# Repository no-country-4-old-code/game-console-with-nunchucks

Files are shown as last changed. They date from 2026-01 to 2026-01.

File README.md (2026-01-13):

# Simple Game Console Based on AtMega87-20PU
This is a minimal gaming console based on two AtMega-MCUs.
The input is done via two old "Wii"-Nunchucks.
Output is given via monitor (VGA) and scores are displayed via 7-segment-displays.

The whole thing is rather old (2013), but I had a lot of fun building it.
In other words: Do not expect much regarding clean code etc.

I translate the original documentation into english using AI and put it below.
And yes.. I did a documentation.. but only because this was needed to publish the project on Heise.
The original documentation with all the nice pictures is also in the repo.

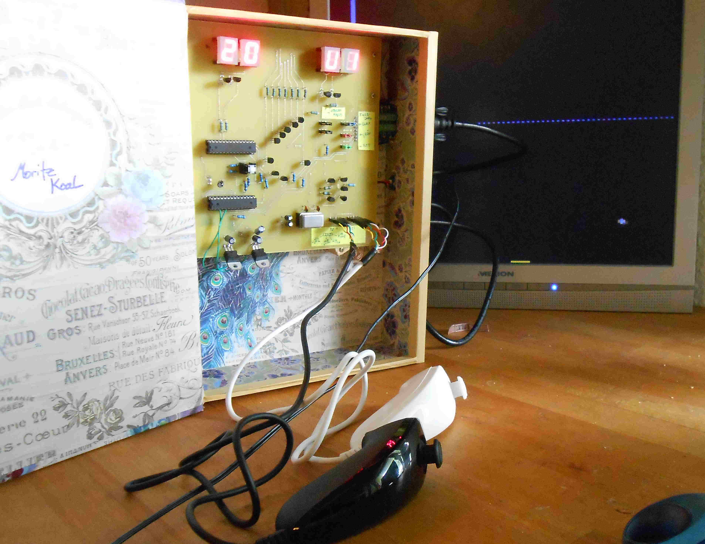
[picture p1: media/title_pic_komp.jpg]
GameConsole


## Documentation (Translated by AI)

## Project Overview

This repository documents a simple video game console that runs the classic game **"Pong"** on a standard VGA monitor, controlled by two Wii Nunchuks. The hardware is powered by just two AtMega88-20PU microcontrollers, and the implementation showcases the technical challenges of VGA signal generation and game logic with limited resources.

## Features

**VGA Output**  
The console directly drives a VGA monitor in 640×480 @60Hz mode, outputting all graphics using the AtMega88 microcontroller. The graphics pipeline and Pong gameplay logic are written in Assembler for maximum performance.

**Controller Support**  
Two original Wii Nunchuks serve as input devices. Their joysticks and accelerometers allow paddle control, selectable via board jumpers. Communication is handled via I²C/TWI.

**Score Display**  
An array of four seven-segment displays shows the current score. Multiplexing and updates are managed in C, running on the second AtMega.

**Additional Controls**  
The board features jumpers for color/mode selection, a reset/start button, and three output pins as triggers for a simple sound system (optional, not included).

**Efficient Communication**  
The microcontrollers communicate via a custom UART protocol for fast score and control updates.

## Technical Highlights

### VGA Module

This unit is responsible for image generation, VGA signaling, game mechanics, and data transfer to the controller module. With the VGA protocol being extremely timing-sensitive, the implementation uses Assembler and overclocks the AtMega88 to 22.1145 MHz.  
The software architecture separates graphics generation (run at 5.5 MHz "pixel clock") and game logic into distinct processes, with a timer ISR acting as the scheduler.

### Controller Module

Implemented in C, this module polls the Nunchuks, manages scores, updates the seven-segment displays, and coordinates with the VGA module via UART. Nunchuk polling and game state updates are all performed within a single frame to maintain responsiveness.

### Hardware Design

Most circuit details are derived from the AtMega88 datasheet and well-known application notes (e.g., Philips AN97055 for level shifting). Special consideration is given to transistor pin layouts, with corrective diagrams provided for BC640 and BS108 variants.

## Notes on VGA Implementation

- **Pixel Clock Limitations:** The microcontroller cannot match the standard 25 MHz VGA pixel clock. Instead, output occurs at roughly 5.5 MHz, resulting in horizontally stretched pixels—but reliable display.
- **Memory Handling:** Graphics data is loaded into SRAM at startup for fast access; worklines and images are organized for efficient redrawing of game elements.
- **UART Datagram:** The UART protocol is custom-designed, using 8 data bits, one stop bit, and a baud rate of 32,143 Kbps.

## Images & Schematics

Key diagrams illustrating VGA timing, connector layouts, software architecture, datagram structure, and transistor pinouts are included in the documentation.

---

### Author

**Moritz Koal** (2013)

---

## Caution on Hardware Layout

When assembling, pay close attention to transistor pin assignments—especially for BC640 (swap collector and base) and BS108 (rotate drain and source by 180°). Refer to the included diagrams and datasheets for exact orientation.

---

## License

Feel free to modify, share, and build upon this project for educational or personal use.

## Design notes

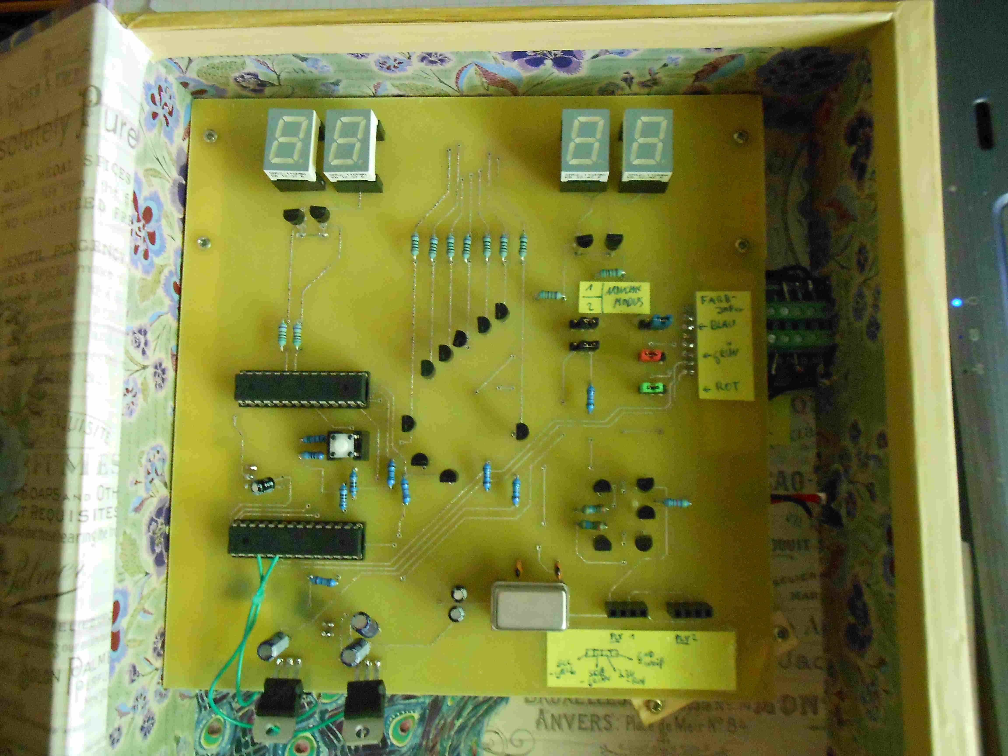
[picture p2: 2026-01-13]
media/von_oben_komp.jpg

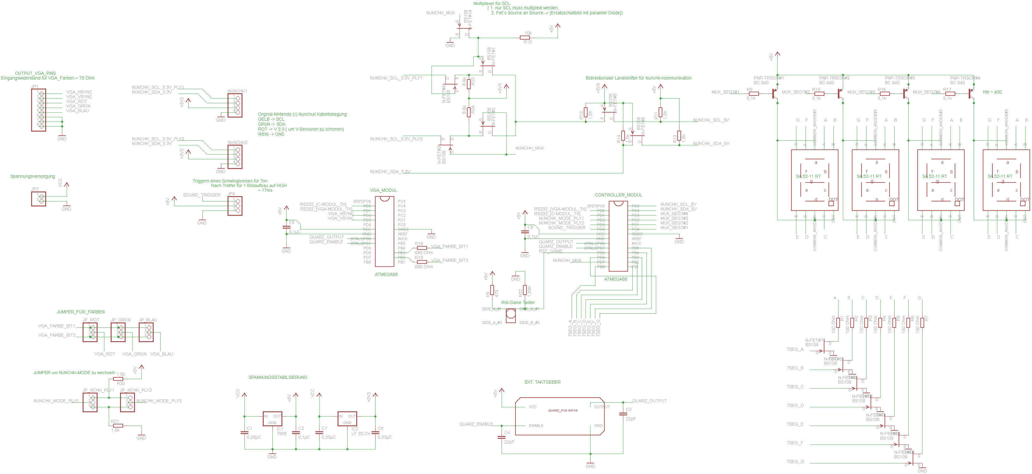
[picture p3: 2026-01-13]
hw/Schaltplan_Spielekonsole.png

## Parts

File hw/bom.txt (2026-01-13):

Stückliste

//======== Eagle

Qty Value            Device             Package                Parts                                                                                                                             Description                
1                    PINHD-1X2          1X02                   JP2                                                                                                                               PIN HEADER                 
6                    PINHD-1X3          1X03                   JP4, JP_BLAU, JP_GRÜN, JP_NCHK_PLY1, JP_NCHK_PLY2, JP_ROT                                                                         PIN HEADER                 
2                    PINHD-1X4          1X04                   NUNCHK1, NUNCHK2                                                                                                                  PIN HEADER                 
1                    PINHD-1X8          1X08                   JP1                                                                                                                               PIN HEADER                 
3   0,1µC            C-EU025-024X044    C025-024X044           C2, C5, C6                                                                                                                        CAPACITOR, European symbol 
3   0,33µC           C-EU025-024X044    C025-024X044           C1, C7, C8                                                                                                                        CAPACITOR, European symbol 
1   1,58k            R-EU_0204/7        0204/7                 R22                                                                                                                               RESISTOR, European symbol  
6   1,5k             R-EU_0204/7        0204/7                 R11, R12, R13, R14, R20, R21                                                                                                      RESISTOR, European symbol  
7   100 Ohm          R-EU_0204/7        0204/7                 R1, R2, R3, R4, R5, R6, R7                                                                                                        RESISTOR, European symbol  
1   10k              R-EU_0204/7        0204/7                 R15                                                                                                                               RESISTOR, European symbol  
2   22pF             C-EU025-024X044    C025-024X044           C3, C4                                                                                                                            CAPACITOR, European symbol 
1   470              R-EU_0204/7        0204/7                 R8                                                                                                                                RESISTOR, European symbol  
4   5,1k             R-EU_0204/7        0204/7                 R9, R10, R16, R17                                                                                                                 RESISTOR, European symbol  
2   680 Ohm          R-EU_0204/7        0204/7                 R18, R19                                                                                                                          RESISTOR, European symbol  
1   7805             78XXL              78XXL                  IC1                                                                                                                               VOLTAGE REGULATOR          
2   8,6k             R-EU_0204/7        0204/7                 R23, R24                                                                                                                          RESISTOR, European symbol  
2   ATMEGA 88-20 PU  ATMEGA8            ATMEGA8_PAC            U$1, U$2                                                                                                                                                     
4   BC 640           2N4126             TO92-CBE               PNP-TRSOR#1, PNP-TRSOR#2, PNP-TRSOR#3, PNP-TRSOR#4                                                                                PNP Transistror            
14  BS108            2N3819             TO92                   N-FET#1, N-FET#2, N-FET#3, N-FET#4, N-FET#5, N-FET#6, N-FET#7, N-FET#8, N-FET#9, N-FET#10, N-FET#11, N-FET#12, N-FET#13, N-FET#14 N-Channel Junction FET     
1   LF 33 CV         78XXL              78XXL                  IC2                                                                                                                               VOLTAGE REGULATOR          
1   QUARZ_PX0_DIP14  QUARZ_PX0_DIP14    QUARZ_PX0_DIP14_PAC    U$3                                                                                                                                                          
4   SA 52-11 RT      SIEBEN_SEG_SA52-11 SIEBEN_SEG_SA52-11_PAC U$4, U$5, U$6, U$7                                                                                                                                           
1   TASTER_1         TASTER_1           TASTER_1_PAC           U$8                                                                                                                                                          

//========== Sonstiges 

2  *	GS 28P-S		IC-Sockel für Atmega88
5  *	MPE 087-1-003		Stiftleisten mit 2,54mm ( für Jumper )
5  *	Jumper 2,54mm		Zur Auswahl Joystick/Beschleunigungssensor etc
8  *	MPE 094-1-005		Buchsenleiste,1X05 2,54mm für Siebensegment Blöcke
4  *	MPE 094-1-004		Buchsenleiste,1X04 2,54mm für Quarz und Nunchucks
2  *	MPE 087-1-004		Stiftleiste,1X04 2,54mm für Nunchucks ( Besser wäre natürlich ein Adapter, so dass man die Nunchucks nicht aufschneiden muss )
1  *	Tastschalter + gegebenfalls entsprechende Buchsenleisten ( z.B. FSM2JH + 2* MPE 094-1-003 )
1  * 	DELOCK 65170		16 Pin, VGA-Buchse <-> Terminalblock. ( Erleichtert den Anschluss )

//========== Stromversorgung
1  *	PSAA 18U-090		Kompaktschaltnetzteil , 18 W , 9 V out
1  *	HEBFL 21		Hohlstecker-Einbaubuchse, Flansch, Stift 2,1mm

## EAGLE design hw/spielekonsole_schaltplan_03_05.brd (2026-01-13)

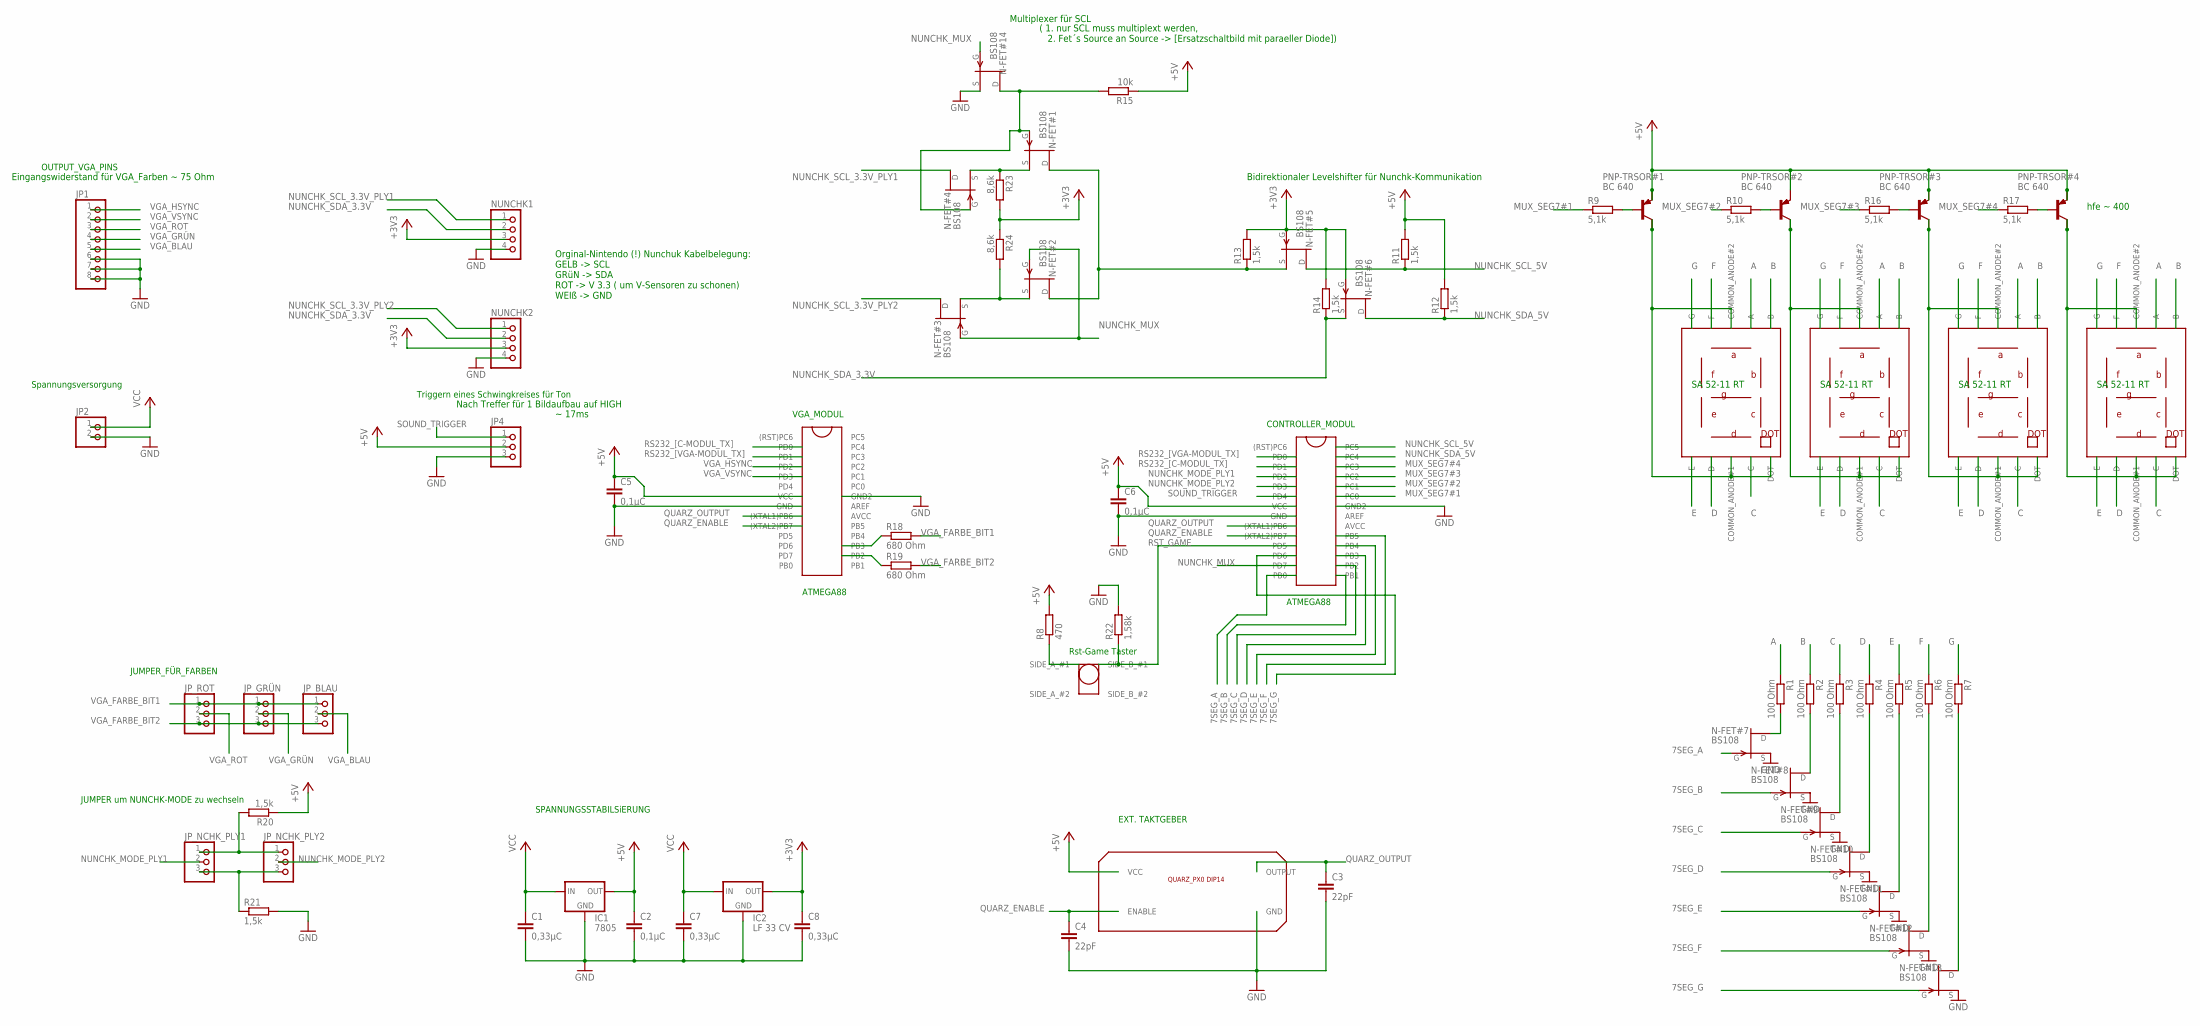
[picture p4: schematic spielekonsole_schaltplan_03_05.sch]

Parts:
C1, C7, C8: 0,33µC; C025-024X044
C2, C5, C6: 0,1µC; C025-024X044
C3, C4: 22pF; C025-024X044
IC1: 7805; 78XXL
IC2: LF 33 CV; 78XXL
JP1: PINHD-1X8; 1X08
JP2: PINHD-1X2; 1X02
JP4: PINHD-1X3; 1X03
JP_BLAU: PINHD-1X3; 1X03
JP_GRÜN: PINHD-1X3; 1X03
JP_NCHK_PLY1, JP_NCHK_PLY2: PINHD-1X3; 1X03
JP_ROT: PINHD-1X3; 1X03
N-FET#1, N-FET#2, N-FET#3, N-FET#4, N-FET#5, N-FET#6, N-FET#7, N-FET#8, N-FET#9, N-FET#10, N-FET#11, N-FET#12, N-FET#13, N-FET#14: BS108; TO92
NUNCHK1, NUNCHK2: PINHD-1X4; 1X04
PNP-TRSOR#1, PNP-TRSOR#2, PNP-TRSOR#3, PNP-TRSOR#4: BC 640; TO92-CBE
R1, R2, R3, R4, R5, R6, R7: 100 Ohm; 0204/7
R8: 470; 0204/7
R9, R10, R16, R17: 5,1k; 0204/7
R11, R12, R13, R14, R20, R21: 1,5k; 0204/7
R15: 10k; 0204/7
R18, R19: 680 Ohm; 0204/7
R22: 1,58k; 0204/7
R23, R24: 8,6k; 0204/7
U$1, U$2: ATMEGA 88-20 PU; ATMEGA8_PAC
U$3: QUARZ_PX0_DIP14; QUARZ_PX0_DIP14_PAC
U$4, U$5, U$6, U$7: SA 52-11 RT; SIEBEN_SEG_SA52-11_PAC
U$8: TASTER_1; TASTER_1_PAC

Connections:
7SEG_A: N-FET#7.2 (G), U$2.PB0
7SEG_B: N-FET#8.2 (G), U$2.PB1
7SEG_C: N-FET#9.2 (G), U$2.PB2
7SEG_D: N-FET#10.2 (G), U$2.PB3
7SEG_E: N-FET#11.2 (G), U$2.PB4
7SEG_F: N-FET#12.2 (G), U$2.PB5
7SEG_G: N-FET#13.2 (G), U$2.PD6
+3V3: C8.1, IC2.OUT, N-FET#5.2 (G), N-FET#6.2 (G), NUNCHK1.3, NUNCHK2.3, R13.2, R14.2, R23.2, R24.1
+5V: C2.1, C5.1, C6.1, IC1.OUT, JP4.2, PNP-TRSOR#1.E, PNP-TRSOR#2.E, PNP-TRSOR#3.E, PNP-TRSOR#4.E, R8.2, R11.2, R12.2, R15.1, R20.1, U$1.VCC, U$2.VCC, U$3.VCC
A: R1.1, U$4.A, U$5.A, U$6.A, U$7.A
B: R2.1, U$4.B, U$5.B, U$6.B, U$7.B
C: R3.1, U$4.C, U$5.C, U$6.C, U$7.C
D: R4.1, U$4.D, U$5.D, U$6.D, U$7.D
E: R5.1, U$4.E, U$5.E, U$6.E, U$7.E
ENABLE_SEG7#1: PNP-TRSOR#1.C, U$4.COMMON_ANODE#1, U$4.COMMON_ANODE#2, U$4.DOT
ENABLE_SEG7#2: PNP-TRSOR#2.C, U$5.COMMON_ANODE#1, U$5.COMMON_ANODE#2, U$5.DOT
ENABLE_SEG7#3: PNP-TRSOR#3.C, U$6.COMMON_ANODE#1, U$6.COMMON_ANODE#2, U$6.DOT
ENABLE_SEG7#4: PNP-TRSOR#4.C, U$7.COMMON_ANODE#1, U$7.COMMON_ANODE#2, U$7.DOT
F: R6.1, U$4.F, U$5.F, U$6.F, U$7.F
G: R7.1, U$4.G, U$5.G, U$6.G, U$7.G
GND: C1.2, C2.2, C3.2, C4.2, C5.2, C6.2, C7.2, C8.2, IC1.GND, IC2.GND, JP1.6, JP1.7, JP1.8, JP2.2, JP4.3, N-FET#7.3 (S), N-FET#8.3 (S), N-FET#9.3 (S), N-FET#10.3 (S), N-FET#11.3 (S), N-FET#12.3 (S), N-FET#13.3 (S), N-FET#14.3 (S), NUNCHK1.4, NUNCHK2.4, R21.2, R22.2, U$1.GND1 (GND), U$1.GND2, U$2.GND1 (GND), U$2.GND2, U$3.GND
MUX_SEG7#1: R9.1, U$2.PC0
MUX_SEG7#2: R10.1, U$2.PC1
MUX_SEG7#3: R16.1, U$2.PC2
MUX_SEG7#4: R17.1, U$2.PC3
unnamed: R8.1, U$8.SIDE_A_#1
unnamed: PNP-TRSOR#1.B, R9.2
unnamed: PNP-TRSOR#2.B, R10.2
unnamed: PNP-TRSOR#3.B, R16.2
unnamed: PNP-TRSOR#4.B, R17.2
unnamed: R18.1, U$1.PB3
unnamed: R19.1, U$1.PB2
unnamed: JP_NCHK_PLY1.3, JP_NCHK_PLY2.3, R21.1
unnamed: N-FET#1.2 (G), N-FET#4.2 (G), N-FET#14.1 (D), R15.2
unnamed: JP_NCHK_PLY1.1, JP_NCHK_PLY2.1, R20.2
unnamed: N-FET#1.1 (D), N-FET#2.1 (D), N-FET#5.3 (S), R13.1
unnamed: N-FET#1.3 (S), N-FET#4.3 (S), R23.1
unnamed: N-FET#2.3 (S), N-FET#3.3 (S), R24.2
unnamed: N-FET#7.1 (D), R1.2
unnamed: N-FET#8.1 (D), R2.2
unnamed: N-FET#9.1 (D), R3.2
unnamed: N-FET#10.1 (D), R4.2
unnamed: N-FET#11.1 (D), R5.2
unnamed: N-FET#12.1 (D), R6.2
unnamed: N-FET#13.1 (D), R7.2
NUNCHK_MODE_PLY1: JP_NCHK_PLY1.2, U$2.PD2
NUNCHK_MODE_PLY2: JP_NCHK_PLY2.2, U$2.PD3
NUNCHK_MUX: N-FET#2.2 (G), N-FET#3.2 (G), N-FET#14.2 (G), U$2.PD7
NUNCHK_SCL_3.3V_PLY1: N-FET#4.1 (D), NUNCHK1.1
NUNCHK_SCL_3.3V_PLY2: N-FET#3.1 (D), NUNCHK2.1
NUNCHK_SCL_5V: N-FET#5.1 (D), R11.1, U$2.PC5
NUNCHK_SDA_3.3V: N-FET#6.3 (S), NUNCHK1.2, NUNCHK2.2, R14.1
NUNCHK_SDA_5V: N-FET#6.1 (D), R12.1, U$2.PC4
QUARZ_ENABLE: C4.1, U$1.PB7 ((XTAL2)PB7), U$2.PB7 ((XTAL2)PB7), U$3.ENABLE
QUARZ_OUTPUT: C3.1, U$1.PB6 ((XTAL1)PB6), U$2.PB6 ((XTAL1)PB6), U$3.OUTPUT
RS232_[C-MODUL_TX]: U$1.PD0, U$2.PD1
RS232_[VGA-MODUL_TX]: U$1.PD1, U$2.PD0
RST_GAME: R22.1, U$2.PD5, U$8.SIDE_B_#1
SOUND_TRIGGER: JP4.1, U$2.PD4
VCC: C1.1, C7.1, IC1.IN, IC2.IN, JP2.1
VGA_BLAU: JP1.5, JP_BLAU.2
VGA_FARBE_BIT1: JP_BLAU.1, JP_GRÜN.1, JP_ROT.1, R18.2
VGA_FARBE_BIT2: JP_BLAU.3, JP_GRÜN.3, JP_ROT.3, R19.2
VGA_GRÜN: JP1.4, JP_GRÜN.2
VGA_HSYNC: JP1.1, U$1.PD2
VGA_ROT: JP1.3, JP_ROT.2
VGA_VSYNC: JP1.2, U$1.PD3

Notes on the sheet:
OUTPUT_VGA_PINS
JUMPER_FÜR_FARBEN
VGA_MODUL
SPANNUNGSSTABILSiERUNG
Spannungsversorgung
EXT. TAKTGEBER
CONTROLLER_MODUL
ATMEGA88
JUMPER um NUNCHK-MODE zu wechseln
Triggern eines Schwingkreises für Ton
Rst-Game Taster
Orginal-Nintendo (!) Nunchuk Kabelbelegung: GELB -> SCL GRüN -> SDA ROT -> V 3.3 ( um V-Sensoren zu schonen) WEIß -> GND
Multiplexer für SCL
Bidirektionaler Levelshifter für Nunchk-Kommunikation
hfe ~ 400
Eingangswiderstand für VGA_Farben ~ 75 Ohm
Nach Treffer für 1 Bildaufbau auf HIGH
~ 17ms
( 1. nur SCL muss multiplext werden, 2. Fet´s Source an Source -> [Ersatzschaltbild mit paraeller Diode])
SA 52-11 RT

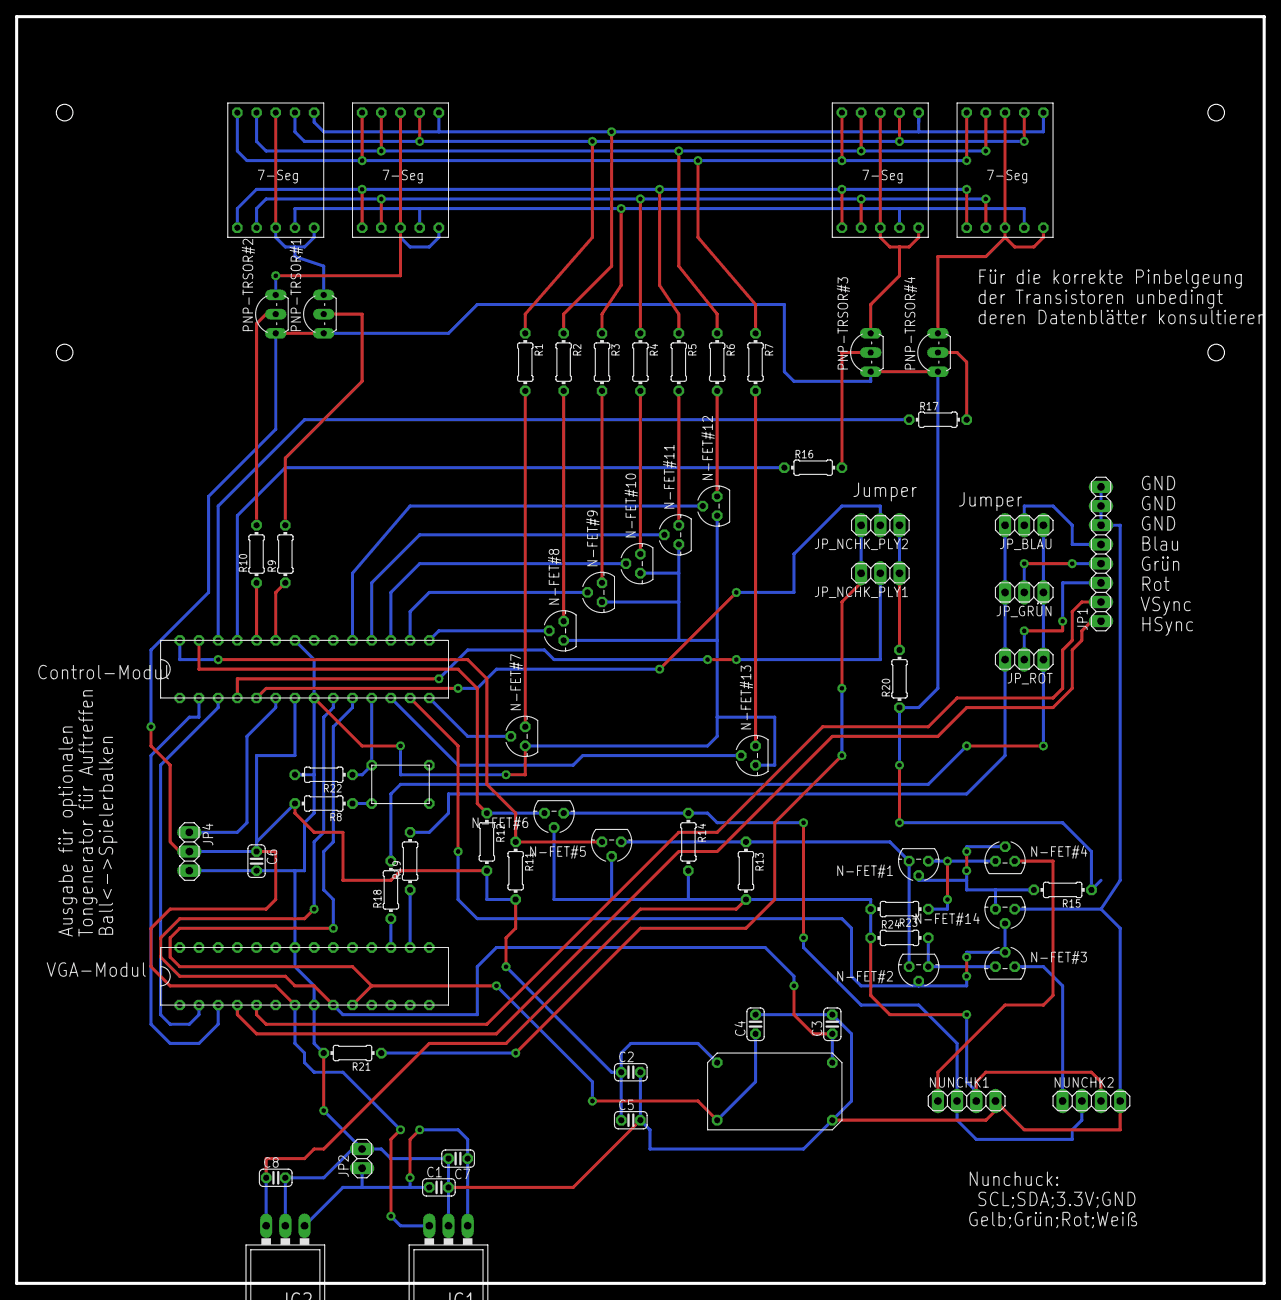
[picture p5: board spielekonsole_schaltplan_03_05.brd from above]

Board: 2 copper layers, 165.1 x 167.6 mm, 70 parts (0 on the bottom side), 67 nets.

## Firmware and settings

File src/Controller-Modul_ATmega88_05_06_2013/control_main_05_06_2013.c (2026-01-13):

/*
 * Project_C.c
 *
 * Created: 24.11.2012 17:46:01
 *  Author: mo
 */ 
//Include Header Dateien in
// C:\Program Files\Atmel\Atmel Studio 6.0\extensions\Atmel\AVRGCC\3.4.0.65\AVRToolchain\avr\include\avr


#define F_CPU 21145000UL

#include <avr/io.h>
#include <string.h>
#include <avr/interrupt.h>
#include <util/delay.h>
#include "uart.h"
#include "twi_routines.h"
#include "funktions.h"


// Rst Knopf
#define RST_PORT PORTD
#define RST_PINS PIND
#define RST_DDR DDRD
#define RST_PIN PD5
#define RST_ACTIV 1 // High Aktiv

// Watchdog
#define BORDER_WATCHDOG 21 // Ein Timer ISR wird standardmäßig mit 60Hz ausgelöst sprich alle 16,6 ms -> Multiplexing geschieht alle 1,6 ms; Grenze wird mit 21 angegeben


// Nunchk-Mode auswählen ( Stick oder Beschleunigungssensor auslesen )
#define NUNCHK_MODE_PORT PORTD
#define NUNCHK_MODE_PINS PIND
#define NUNCHK_MODE_DDR DDRD
#define NUNCHK_MODE_PIN_PLY1 PD2
#define NUNCHK_MODE_PIN_PLY2 PD3
#define NUNCHK_MODE_STICK 1
#define NUNCHK_MODE_VSENSOR 0
#define NUNCHK_MODE_STICK_SEGMENT 0
#define NUNCHK_MODE_VSENSOR_SEGMENT 2


// 'Pong'-Ton Ausgabe
#define SOUND_PORT PORTD
#define SOUND_DDR DDRD
#define SOUND_PIN PD4
#define SOUND_AKTIV 1 // immer über einen Zyklus (also ~ 1/60 s aktiv -> außer beim aufhängen .... ) -> abfange routine in Timer-ISR

// SiebenSeg
#define SEG7_OUTPUT1_PORT PORTB
#define SEG7_OUTPUT2_PORT PORTD
#define SEG7_OUTPUT1_DDR DDRB
#define SEG7_OUTPUT2_DDR DDRD
#define SEG7_OUTPUT_PINS1  0b00111111//(1<<PB0)|(1<<PB1)|(1<<PB2)|(1<<PB3)|(1<<PB4)|(1<<PB5)  //0b00111111 // PB0 bis PB5
#define SEG7_OUTPUT_PINS2  0b01000000//(1<< PD6)  //0b01000000 // PD6 als 7ter Pin
#define NUM_OF_SEG7_DISPLAYS 4
#define NUM_OF_NUMBERS4DISPLAY 10 // Bei Änderung das Array "seg7_umwandlung_zahl2seg7" anpassen !

#define SEG7_MUX_PORT PORTC
#define SEG7_MUX_DDR DDRC
#define SEG7_MUX_PINS 0x0F // PC3:PC0

//Timer0
#define TIMER0_PRESCALER 0x05
#define TIMER0_START_VALUE (255-35) // 35 Takte sollen gezählt werden -> ~1,66 ms


// Nunchk
#define NUNCHUCK_ADR 0x52

#define NUNCHUCK_INIT_1 0xF0 // 1
#define NUNCHUCK_INIT_2 0x55
#define NUNCHUCK_INIT_3 0xFB // 2
#define NUNCHUCK_INIT_4 0x00
#define NUNCHUCK_RST_PTR_RAM 0x00 // 3

#define NUNCHUCK_TIME_INIT_ms 100
#define NUNCHUCK_TIME_RAM_ms 1

#define NUM_OF_NUNCHK_DATA 6

// Für Nunchuck Multiplexer
#define MULTI_NUCHK_PIN PD7
#define MULTIPLI_NUCHK_PORT PORTD
#define MULTIPLI_NUCHK_DDR DDRD
#define TIME_AFTER_CHANGE_NUCHK_us 1
#define NUNCHK_1 0
#define NUNCHK_2 1
#define NUNCHK_CHANGE (1<<MULTI_NUCHK_PIN) // einfach eor mit Nunchk_change um  [ eor ==  ^  ]


// Bewerten einer Bewegung -> Kommunikationsdaten vom Nunchuck
/*nunchk_buffer[     1   ] | [    2    ] | [    3    ] | [    4   ] | [    5     ] | [             6            ] -> 6 Bytes!
 	Bedeutung:	Joystick X | Joystick Y  | V-Sensor X  | V-Sensor Y |  V-Sensor Z  | LSB von X,Y,Z und Knöpfe Z,C 		
*/
#define MOVEMENT_BLANK 0 // welcher Abschnitt wird als Bewegung gewertet
#define MOVEMENT_BORDER_RIGHT 127+30 // Grenzen ab wann Bewegung als Bewegung gezählt werden kann (rausfiltern von Rauschen,leichten Schwankungen)
#define MOVEMENT_BORDER_LEFT 127-30
#define MOVEMENT_BORDER_RIGHT_FAST 127+90
#define MOVEMENT_BORDER_LEFT_FAST 127-90
#define MOVEMENT_RIGHT_PLY1_FAST 0b00000110
#define MOVEMENT_RIGHT_PLY2_FAST 0b00110000
#define MOVEMENT_RIGHT_PLY1 0b00000101
#define MOVEMENT_RIGHT_PLY2 0b00101000
#define MOVEMENT_LEFT_PLY1_FAST	0b00000010
#define MOVEMENT_LEFT_PLY2_FAST	0b00010000
#define MOVEMENT_LEFT_PLY1	0b00000001
#define MOVEMENT_LEFT_PLY2	0b00001000
/*
Kommando für VGA-MODUL : 
Aufbau Protokoll ( C-Modul -> VGA-Modul ) : [ 7:6 | 5:3 | 2:0  ]  == [ 11=rst | BewegungPlayer2 | BewegungPlayer1 ]
*/
#define CMD4VGA_RESET 0b11000000

/*
Kommando für C-MODUL : 
Aufbau Protokoll ( VGA-Modul -> C-Modul ) : [ 7:2 | 1 | 0 ] == [ reserviert ( zu belegen mit "101010" ) | ÄnderungSpielstand2 | ÄnderungSpielstand1 ]
*/
#define CMD4C_NORMAL 0b10101000
#define CMD4C_MASK_POINT_PLY1 0x01
#define CMD4C_MASK_POINT_PLY2 0x02





void nunchuck_init(void);
void nunchuck_receiveData(uint8_t *buffer);
void display_7_segmentanzeige(void);

//globale Variabeln (volatile für ISR-Verwendbarkeit)

volatile uint8_t cmd_data=CMD4VGA_RESET; // enthält zu sendendes Kommando für das VGA-Modul
volatile uint8_t seg7_aktive_anzeige=0; // gibt an welche anzeige grade aktiv ist ( notwendig aufgrund multiplexing )
volatile uint8_t watchdog_counter=0; //Reagiert wenn lange keine RSR232-ISR mehr ausgeführt wurde, um Deadlock zu verhindern. 
uint8_t volatile seg7_zahlenwerte[NUM_OF_SEG7_DISPLAYS]={1,2,3,4}; // die jeweiligen Zahlenwerte ,die angezeigt werden sollen ( 1:0 [Player1] ; 3:2 [Player2] )
uint8_t volatile seg7_umwandlung_zahl2seg7[NUM_OF_NUMBERS4DISPLAY]={0x3F,0x06,0x5B,0x4F,0x66,0x6D,0x7D,0x07,0x7F,0x6F}; // High-aktiv [ hat eine Treiberstufe dahinter ] , Zahlen 0 bis 9
uint8_t volatile seg7_multiplex_werte[NUM_OF_SEG7_DISPLAYS]={0x07,0x0B,0x0D,0x0E}; // PC3:PC0 // LOW Aktiv



uint8_t tmp=0;



//char nunchk_output[42];


int main(void)
{	
	cli();
	// Init RST_PIN
	RST_DDR&=(~(1<<RST_PIN)); // ist ein Eingang !
	RST_PORT&=(~(1<<RST_PIN));
	
	// Init Sound Pin
	SOUND_PORT&=~(SOUND_AKTIV<<SOUND_PIN); // Startet im inaktiven Zustand
	SOUND_DDR|=(1<<SOUND_PIN);
	
	// Init Nunchk_mode Pins
	NUNCHK_MODE_PORT&=~((1<< NUNCHK_MODE_PIN_PLY1 ) | ( 1<< NUNCHK_MODE_PIN_PLY2));
	NUNCHK_MODE_DDR&=~((1<< NUNCHK_MODE_PIN_PLY1 ) | ( 1<< NUNCHK_MODE_PIN_PLY2));
	
	// Init Siebensegmentanzeige + deren Multiplexer
	SEG7_OUTPUT1_DDR|=SEG7_OUTPUT_PINS1;
	SEG7_OUTPUT2_DDR|=SEG7_OUTPUT_PINS2;
	SEG7_MUX_DDR|=SEG7_MUX_PINS;
	SEG7_OUTPUT1_PORT&=~SEG7_OUTPUT_PINS1;
	SEG7_OUTPUT2_PORT|=SEG7_OUTPUT_PINS2;
	SEG7_MUX_PORT&=~SEG7_MUX_PINS;
	
	// Init TimerISR
	TCCR0B=TIMER0_PRESCALER;
	TCNT0=TIMER0_START_VALUE;
	TIMSK0|=(1<<TOIE0); // ISR enablen
	
	// Init des Multiplexers für Nunchuck
	tmp = (1 << MULTI_NUCHK_PIN);
	MULTIPLI_NUCHK_DDR |= tmp;
	MULTIPLI_NUCHK_PORT &= ~tmp;
	
	// Init der Nunchuks
	twi_master_init();	

	MULTIPLI_NUCHK_PORT&=(~(1<<MULTI_NUCHK_PIN)); //ändert des Multiplexers auf Nuchk1
	_delay_ms(TIME_AFTER_CHANGE_NUCHK_us);
	nunchuck_init(); //Nunchuk in decodierten Modus versetzen
	MULTIPLI_NUCHK_PORT^=NUNCHK_CHANGE;
	_delay_ms(TIME_AFTER_CHANGE_NUCHK_us); // Berücksichtigen der Rise and Fall Time des MultiplexerTransistors
	nunchuck_init(); //Nunchuk in decodierten Modus versetzen
	MULTIPLI_NUCHK_PORT^=NUNCHK_CHANGE;
	_delay_ms(TIME_AFTER_CHANGE_NUCHK_us); // Berücksichtigen der Rise and Fall Time des MultiplexerTransistors



	USART_Init(42);
	//für RX-ISR	
	UCSR0B|= (1<<RXCIE0);

	display_7_segmentanzeige();
	
	cmd_data=CMD4VGA_RESET; //Vorher Reset damit auch alles Schön aussieht
	USART_Transmit(cmd_data);
	cmd_data=0;
	
	// Warten auf Knopfdruck
	tmp=RST_PINS & (RST_ACTIV<<RST_PIN);
	
	while(tmp!=(RST_ACTIV<<RST_PIN)){
		tmp=RST_PINS & (RST_ACTIV<<RST_PIN);
	};		
		
	// Reseten vom VGA-Modul 
	cmd_data=CMD4VGA_RESET;
	USART_Transmit(cmd_data);
	cmd_data=0;
	sei();

	
	while(1)
    { 		
	display_7_segmentanzeige();
	if(watchdog_counter>=BORDER_WATCHDOG){
		cmd_data=MOVEMENT_BLANK;  //Vermeidung von Dead-Locks
		USART_Transmit(cmd_data); //ein dummy losschicken, um anderen anzutriggern (der wartet auf eine Antwort) 
		watchdog_counter=0;
		}
	};
	
}


// Funktion zum Ansteuern der 7 Seg Anzeige
// langer Interrupt ,wobei nur anfang ununterbrechbar ist 
ISR(USART_RX_vect){
	cli();
	
	uint8_t new_data;
	uint8_t cmd_prototyp=MOVEMENT_BLANK;
	uint8_t nunchk_buffer[NUM_OF_NUNCHK_DATA];
	uint8_t nunchk_mode=NUNCHK_MODE_STICK_SEGMENT; // Default auf Stick
	
	new_data=UDR0; // liest Zeichen und speichert es in new_data
	
	SOUND_PORT&=~(SOUND_AKTIV<<SOUND_PIN); // Sound aus

	USART_Transmit(cmd_data); 	// sendet Bewegungsbefehle (vorher schon beschlossen)
	
	// wertet Zeichen aus und greift auf 7-Segmentdata zu -> ( 1:0 [Player1] ; 3:2 [Player2] )
	tmp=new_data;
	sei();
	watchdog_counter=0;
	tmp=new_data;
	
	tmp&=CMD4C_MASK_POINT_PLY1;
	//tmp/=CMD4C_MASK_POINT_PLY1; // ergibt 1 bei Übereinstimmung,ansosnten null
// Punkt Sound
	if(tmp==1){	
		SOUND_PORT|=(SOUND_AKTIV<<SOUND_PIN);
	}
	seg7_zahlenwerte[0]+=tmp;
	tmp=seg7_zahlenwerte[0]/NUM_OF_NUMBERS4DISPLAY; // 1 beim übereinstimmen
	seg7_zahlenwerte[0]=seg7_zahlenwerte[0]%NUM_OF_NUMBERS4DISPLAY; // 0 beim Ende des Zahlenspektrums
	seg7_zahlenwerte[1]+=tmp; // wird ein hochgezählt
	seg7_zahlenwerte[1]=seg7_zahlenwerte[1]%NUM_OF_NUMBERS4DISPLAY; // 0 beim Ende des Zahlenspektrums
		
	tmp=new_data;

	tmp&= CMD4C_MASK_POINT_PLY2;
	tmp=tmp >> 1;
	//tmp/=CMD4C_MASK_POINT_PLY2; // ergibt 1 bei Übereinstimmung,ansosnten null
// Punkt Sound
	if(tmp==1){	
		SOUND_PORT|=(SOUND_AKTIV<<SOUND_PIN);
	}
	seg7_zahlenwerte[2]+=tmp;
	tmp=seg7_zahlenwerte[2]/NUM_OF_NUMBERS4DISPLAY; // 1 beim übereinstimmen
	seg7_zahlenwerte[2]=seg7_zahlenwerte[2]%NUM_OF_NUMBERS4DISPLAY; // 0 beim Ende des Zahlenspektrums
	seg7_zahlenwerte[3]+=tmp; // wird ein hochgezählt
	seg7_zahlenwerte[3]=seg7_zahlenwerte[3]%NUM_OF_NUMBERS4DISPLAY; // 0 beim Ende des Zahlenspektrums
	
	
// nur bei Rst zurücksetzen

		
	
//Holen && Auswerten der Daten
/*nunchk_buffer[     1   ] | [    2    ] | [    3    ] | [    4   ] | [    5     ] | [             6            ]
		Bedeutung:	Joystick X | Joystick Y  | V-Sensor X  | V-Sensor Y |  V-Sensor Z  | LSB von X,Y,Z und Knöpfe Z,C 
*/

// MOVEMENT_UNIT -> JOYSTICKX,JOYSTICKY,V-SENSORX,V-SENSORY,V-SENSOR ;

	display_7_segmentanzeige();	

//=== Mode für Nunchk1 bestimmen === [Ob Stick oder V-Sensor für Bewegung relevant -> wird extern über Jumper netschieden ]	

	tmp=NUNCHK_MODE_PINS;
	tmp&=(1<<NUNCHK_MODE_PIN_PLY1);
	if(tmp==(NUNCHK_MODE_STICK<<NUNCHK_MODE_PIN_PLY1)){
		nunchk_mode=NUNCHK_MODE_STICK_SEGMENT;
	}
	else{
		nunchk_mode=NUNCHK_MODE_VSENSOR_SEGMENT;
	}
	
	
//=== Daten vom Nunchk 1 holen ===
	nunchuck_receiveData(&nunchk_buffer[0]);
	
	MULTIPLI_NUCHK_PORT^=NUNCHK_CHANGE;
	_delay_ms(TIME_AFTER_CHANGE_NUCHK_us); // Berücksichtigen der Rise and Fall Time des MultiplexerTransistors

	if(nunchk_buffer[nunchk_mode]>=(MOVEMENT_BORDER_RIGHT_FAST)){
		cmd_prototyp|=MOVEMENT_RIGHT_PLY1_FAST; // je nach tmp wird nur die richtige Stelle übernommen
	}
	else if(nunchk_buffer[nunchk_mode]>=(MOVEMENT_BORDER_RIGHT))
	{	cmd_prototyp|=MOVEMENT_RIGHT_PLY1; // je nach tmp wird nur die richtige Stelle übernommen
	}
	
	else if(nunchk_buffer[nunchk_mode]<=(MOVEMENT_BORDER_LEFT_FAST)){
		cmd_prototyp|=MOVEMENT_LEFT_PLY1_FAST;
	}
	else if(nunchk_buffer[nunchk_mode]<=(MOVEMENT_BORDER_LEFT)){
		cmd_prototyp|=MOVEMENT_LEFT_PLY1;
	}


//===== fertig mit Nunchk1 , weiter zu Nunchk2 =====
	display_7_segmentanzeige();
//=== Mode für Nunchk2 bestimmen ===
	tmp=NUNCHK_MODE_PINS;
	tmp&=(1<<NUNCHK_MODE_PIN_PLY2);
	if(tmp==(NUNCHK_MODE_STICK<<NUNCHK_MODE_PIN_PLY2)){
		nunchk_mode=NUNCHK_MODE_STICK_SEGMENT;
	}
	else{
		nunchk_mode=NUNCHK_MODE_VSENSOR_SEGMENT;
	}


//=== Daten vom Nunchk 2 holen ===	
	nunchuck_receiveData(&nunchk_buffer[0]);
	MULTIPLI_NUCHK_PORT^=NUNCHK_CHANGE;
	_delay_us(TIME_AFTER_CHANGE_NUCHK_us); // Berücksichtigen der Rise and Fall Time des MultiplexerTransistors

	if(nunchk_buffer[nunchk_mode]>=(MOVEMENT_BORDER_RIGHT_FAST)){
		cmd_prototyp|=MOVEMENT_RIGHT_PLY2_FAST; // je nach tmp wird nur die richtige Stelle übernommen
	}
	else if(nunchk_buffer[nunchk_mode]>=(MOVEMENT_BORDER_RIGHT)){
		cmd_prototyp|=MOVEMENT_RIGHT_PLY2; // je nach tmp wird nur die richtige Stelle übernommen	
		}
	
	else if(nunchk_buffer[nunchk_mode]<=(MOVEMENT_BORDER_LEFT_FAST)){
		cmd_prototyp|=MOVEMENT_LEFT_PLY2_FAST;
	}
	
	else if(nunchk_buffer[nunchk_mode]<=(MOVEMENT_BORDER_LEFT)){
			cmd_prototyp|=MOVEMENT_LEFT_PLY2;	
		}

//=== fertig mit Nunchks ===

//=== Rst Pin überprüfen ===
	tmp=RST_PINS;
	tmp&=(RST_ACTIV<<RST_PIN);
		
	if(tmp==(RST_ACTIV<<RST_PIN)){
			//reset
			cmd_prototyp=CMD4VGA_RESET;
			for(tmp=0;tmp<NUM_OF_SEG7_DISPLAYS;tmp++){
				seg7_zahlenwerte[tmp]=0;
			}
		}

//=== fertig -> cmd fürs nächste mal erstellen ===		
	
	
	cmd_data=cmd_prototyp; // Arbeitet mit cmd_prototyp schneller ,da wahr. in Registern 
	cmd_prototyp=0;


	
}	


ISR (TIMER0_OVF_vect){
	cli();
	TCNT0=TIMER0_START_VALUE;
	seg7_aktive_anzeige++;
	watchdog_counter++;
	if(seg7_aktive_anzeige>=NUM_OF_SEG7_DISPLAYS){
		seg7_aktive_anzeige=0;
		}

	sei();
}
void nunchuck_init(void){
	twi_master_transStart();
	twi_master_transAdresseSEND(NUNCHUCK_ADR);
	twi_master_transDaten(NUNCHUCK_INIT_1); // Adresse nunchk Register
	twi_master_transDaten(NUNCHUCK_INIT_2); // Wert für nunchk Register
	twi_master_transStop();
	
	_delay_ms(NUNCHUCK_TIME_INIT_ms);

	
	twi_master_transStart();
	twi_master_transAdresseSEND(NUNCHUCK_ADR);
	
	twi_master_transDaten(NUNCHUCK_INIT_3);
	twi_master_transDaten(NUNCHUCK_INIT_4);
	twi_master_transStop();
	
	
	
	_delay_ms(NUNCHUCK_TIME_INIT_ms);
	
}

void nunchuck_receiveData(uint8_t *buffer){
	
	twi_master_transStart();
	twi_master_transAdresseSEND(NUNCHUCK_ADR);
	twi_master_transDaten(NUNCHUCK_RST_PTR_RAM); // Neu setzen des RAM Pointers
	twi_master_transStop();
	
	_delay_ms(NUNCHUCK_TIME_RAM_ms);
	
	twi_master_transStart();
	twi_master_transAdresseRECEIVE(NUNCHUCK_ADR);
	twi_master_receiveData(buffer,NUM_OF_NUNCHK_DATA);
	twi_master_transStop();
}

void display_7_segmentanzeige(void){ 
	// gibt Werte entsprechend auf der sieben_segmentanzeige aus
	uint8_t tmp=0;
	
	tmp=SEG7_MUX_PORT;
	tmp&=~SEG7_MUX_PINS; // löschen der alten Pinwerte
	tmp=tmp | ((seg7_multiplex_werte[seg7_aktive_anzeige]) & SEG7_MUX_PINS); // draufspielen neuer Werte
	SEG7_MUX_PORT=tmp;

	tmp=SEG7_OUTPUT1_PORT;
	tmp&=~SEG7_OUTPUT_PINS1;
	tmp|=(seg7_umwandlung_zahl2seg7[seg7_zahlenwerte[seg7_aktive_anzeige]]&SEG7_OUTPUT_PINS1);
	SEG7_OUTPUT1_PORT=tmp;
	tmp=SEG7_OUTPUT2_PORT;
	tmp&=~SEG7_OUTPUT_PINS2;
	tmp|=(seg7_umwandlung_zahl2seg7[seg7_zahlenwerte[seg7_aktive_anzeige]]&SEG7_OUTPUT_PINS2); // geht weil PD6 genau das 7ze Bit deckt (ansosnten noch zusätzliche SchiebeOP)
	SEG7_OUTPUT2_PORT=tmp;
}

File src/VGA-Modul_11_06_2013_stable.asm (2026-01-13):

.include "m88def.inc"
/* Dieses Modul steuert den VGA Monitor an und managt den Spielverlauf ( Bewegungen, Ball pos , evt. Rst etc ) -> Ausnahme: Punktestand !! -> C-Modul korntrolliert den
und senden gegebendfalls einen Interrupt!
Dazu kommuniziert es mit dem Controller-Modul über die UART Schnittstelle ( Rs232 8N1 , Baudrate= 221145/(16*(43))*10^3 = 32,1 KBps )
Das Controller-Modul schickt diesem Modul ( VGA-Modul ) die Bewegung ( bzw. Änderung der Position ) und evt. Rst.
Aufbau Protokoll ( C-Modul -> VGA-Modul ) : [ 7:6 | 5:3 | 2:0  ]  == [ 11=rst | BewegungPlayer2 | BewegungPlayer1 ]

Das VGA-Modul schickt dem C-Modul die Änderung der Spielstände und evt. Rsten der Spielstände ( Anzeigen übernimmt das C-Modul über 7-Segment Anzeige ).
Aufbau Protokoll ( VGA-Modul -> C-Modul ) : [ 7:2 | 1 | 0 ] == [ reserviert ( zu belegen mit "101010" ) | ÄnderungSpielstand2 | ÄnderungSpielstand1 ]

*/
//zum Teil finden sich kleinere Anpassungen meist in Form von Magic Numbers (das bedeutet nicht zwangsläufig das alle MagicNumbers auch anpassungen sind. Meist für Maskierung )


// Allgemein 
.equ CLK=221145 //in khz [derbst übertaktet]

.equ sram_anfang=0x0100 //0x0060 ist frühste Addresse -> vorher sind ja noch Register[0x00-0x1F] und I/O Ports [0x20-0x5f] und beim Atmega88 ext- Ports [0x60-0xFF]
.equ replay_zeile=4 //jeden DatenBlock 4 mal wiederholen (=> 4*4 Fragmente)
.equ bytes_per_line=40 //40Byte pro 640Pixel bzw für 160Fragmente je 2 Bit

//Bytes der Images
.equ BYTES_complete_line = bytes_per_line
.equ BYTES_spielerbalken = 7
.equ BYTES_spielball = 4
.equ BYTES_Register=1

//SRAM	
 //Spieldaten für main
.equ databyte_controller=sram_anfang // Protokollaufbau : 8 Nutzbits // [0:2] mov_player1 ; [3:5] mov_player2 ; [6:7] cmd
.equ cmds_for_controller=sram_anfang+BYTES_REGISTER  // beinhaltet die Änderung der Spielstände ( wird an C_Modul geschickt )
.equ pos_Byte_player1=cmds_for_controller+BYTES_REGISTER 
.equ pos_Byte_player2=pos_Byte_player1+BYTES_Register
.equ counter_Bit_player1=pos_Byte_player2+BYTES_Register
.equ counter_Bit_player2=counter_Bit_player1+BYTES_Register
.equ pos_Byte_Ball_x=counter_Bit_player2+BYTES_Register  // an welches Byte das IMG gezeichnet werden soll
.equ counter_Bit_Ball_x=pos_Byte_Ball_x+BYTES_Register // da nur Byteweiseadressiert werden kann, werden IMG geshiftet -> init mit 4 , shift_links=-1,shift_rechts=+1 , {==0 || ==8} -> reset und pos_Byte_Ball_x -- oder ++
.equ pos_Ball_y_low=counter_Bit_Ball_x+BYTES_Register
.equ pos_Ball_y_high=pos_Ball_y_low+BYTES_Register
.equ v_Ball_x_count=pos_Ball_y_high+BYTES_Register
.equ v_Ball_y_count=v_Ball_x_count+BYTES_Register
.equ v_Ball_x_max=v_Ball_y_count+BYTES_Register // Das MSB gibt jeweils die Richtung an [ MSB==1 -> links ; MSB==0 -> rechts ]
.equ v_Ball_y_max=v_Ball_x_max+BYTES_Register  // MSB==1 up ; MSB==0 down
.equ last_input_ply1=v_Ball_y_max+BYTES_Register // zum erstellen von Pseudo-Zufallszahlen
.equ last_input_ply2=last_input_ply1+BYTES_Register //zum erstellen von Pseudo-Zufallszahlen
.equ clocks_since_reset=last_input_ply2+BYTES_Register //zum erstellen von Pseudo-Zufallszahlen
 //Images
.equ sram_IMG_spielerbalken1=clocks_since_reset+BYTES_Register
.equ sram_IMG_spielerbalken2=sram_IMG_spielerbalken1+BYTES_spielerbalken
.equ sram_IMG_spielball_part_1=sram_IMG_spielerbalken2+BYTES_spielerbalken
.equ sram_IMG_spielball_part_2=sram_IMG_spielball_part_1+BYTES_spielball
.equ sram_IMG_spielball_part_3=sram_IMG_spielball_part_2+BYTES_spielball
// Worklinies
.equ sram_linke_seitenbegrenzung=sram_IMG_spielball_part_3+BYTES_spielball
.equ sram_mittellinie=sram_linke_seitenbegrenzung+BYTES_complete_line
.equ sram_spielerbalken_player1=sram_mittellinie+BYTES_complete_line
.equ sram_spielerbalken_player2=sram_spielerbalken_player1+BYTES_complete_line
.equ sram_spielball_part_1=sram_spielerbalken_player2+BYTES_complete_line
.equ sram_spielball_part_2=sram_spielball_part_1+BYTES_complete_line
.equ sram_spielball_part_3=sram_spielball_part_2+BYTES_complete_line

// Anordnung ( wo fängt was an )
.equ start_spielerbalken1_vertikal= 54 // ( Spielerbalken1 wird in ZeileH=0 gezeichnet (sichtbar wirds in ZeileH=0 erst ab ZeileL=47 )
.equ spielerbalken1_high= 3
.equ spielerbalken1_length=BYTES_spielerbalken+1
.equ start_spielerbalken2_vertikal= 9  // ( Spielerbalken2 wird in ZeileH=2 gezeichnet ( sichtbar wird in ZeileH=2 im Bereich ZeileL=0 bis ZeileL=17 )
.equ spielerbalken2_high= 3
.equ spielerbalken2_length=BYTES_spielerbalken+1

.equ offset_null_bits_spielerbalken=10 // Bit_paare
.equ offset_null_bits_spielball=7 // // Bit_paare // hier nur Mittelwert
.equ linke_seitenbegrenzung=5  // in x Richtung -> nur für main relevant
.equ rechte_seitenbegrenzung=35
// bei 480 Bildpunkten liegt die Mitte bei 240 (oha) , da es bei 47 anfängt ,bei 267.. somit bei H=1 , L=12
.equ start_mittellinie= 23 // (die Mittelline wird in ZeileH=1 gezeichnet [ sichtbar komplettes Spektrum von ZeileL {0:255} ] )
.equ breite_mittellinie= 1
.equ Spielball_high= 9 // Bewegt sich über alle Zeilen ( == Bytes die aus Memory Map gelesen werden ) 

//Startpositionen
.equ startpos_spielball_vertikal_low=23
.equ startpos_spielball_vertikal_high=1
.equ startpos_spielball_horizontal=18 // Byteweise Addressierung

.equ startpos_spielerbalken1_horizontal=19
.equ startpos_spielerbalken2_horizontal=19




//Inittailiserungswerte
.equ init_counter_bit=4
.equ init_v_Ball_y_max=0x81
.equ init_v_Ball_y_count=0x01
.equ init_cmds_for_controller=0b10101000

.equ PLAYER_1=1
.equ PLAYER_2=2


//Protokoll c2vga ( bei movment Spielerbalken verwendet und rst-Prüfung )
//  ( 000 = keine Bewegung ; 101 bis 111 schnell bis weniger schnell rechts ; 001 bis 011 schnell bis weniger schnell links )
// bezogen auf die 3 Move Bits des jeweiligen Players
.equ cmd_c2vga_reset=0b11000000

//Stackpointer Positionen
.equ stack_ptr_main_low =LOW(RAMEND-4) // -> - Rücksprungadresse ( 16Bit) und tmp,tmp2, --> 0x45F-0x004 == 0x45B ( high ändert sich nicht!)
.equ stack_ptr_display_vga=stack_ptr_main_low-4 // falls das der Fall ist ,wird der stack_ptr wieder auf "stack_ptr_main_low" gesetzt !
// aus Zeitgründen setzen wir den Stackpointer [bzw SPL] im timer_interrupt einfach IMMER auf "stack_ptr_main_low" nachdem wir XH,XL,tmp,tmp2 gepusht haben!

//UART 
.equ BAUD_RATE_HIGH=0  // da beide mit USRR ==12 arbeiten  -> Baudrate == 22,1145 Mhz /(16*(12+1) == 106,319 Kbps (reicht zeitlich für hin und rück )
.equ BAUD_RATE_LOW=42
.equ UART_CMD_START=42

   // Port C
.equ SYNC_VGA_DDR=DDRD
.equ SYNC_VGA_PORT=PORTD 
.equ RXD=0
.equ TXD=1
.equ H_SYNC=2
.equ V_SYNC=3

// Port D
.equ FARBE_VGA_DDR=DDRB // alle Pins des PORTS sind output! (nehmen leider alle in Beschlag,da maskieren zu lange dauern würde)
.equ FARBE_VGA_PORT=PORTB 
.equ BLACK_WHITE=3
.equ GREEN=2


// Definitionen
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
